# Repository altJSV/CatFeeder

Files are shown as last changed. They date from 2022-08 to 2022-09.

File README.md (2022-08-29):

# CatFeeder
- Автоматическая кормушка для домашних питомцев на esp8266
- Создана на основе оригинального проекта AlexGyver
- Страница проекта AlexGyver (схемы, описания): https://alexgyver.ru/gyverfeed2/
- Исходники скетча AlexGyver: https://github.com/AlexGyver/GyverFeed2/
- Идея переноса на esp8266 Sohm777 https://github.com/sohm777/feeder/

# Особенности
- Oled дисплей 
- Автоматическое выключение экрана при простое
- Управление 2 кнопками
- Полноценный веб интерфейс для управления устройством
- Часы с синхронизацией времени по протоколу NTP
- Управление по MQTT с возможной интеграцией в систему умного дома через Яндекс Алису или Home Asistent
- 4 независимых будильника для кормления в заданное время
- Возможность внеочередного кормления по нажатию кнопки, через веб интерфейс или отправки сообщения в MQTT топик
- Видимость и настройка порции кормления как через веб интерфейс, так и на oled экране
- Обновление прошивки по воздуху

# Компиляция и прошивка
Все использованные библиотеки находятся в папке libraries в архиве проекта. 
Настройки arduino ide для NodeMCU
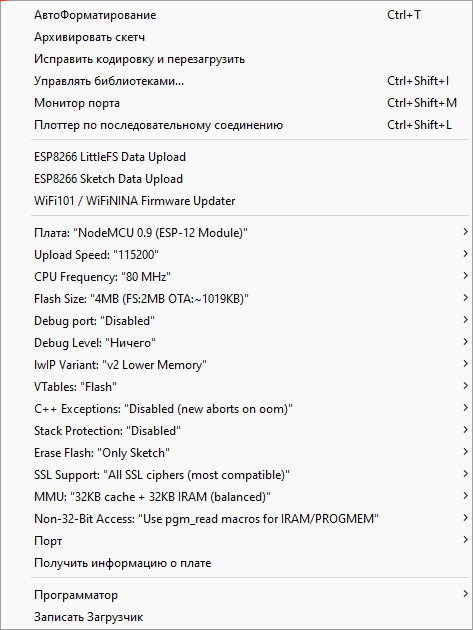
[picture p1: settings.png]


Файловую систему заливать вот по этому гайду https://wikihandbk.com/wiki/ESP8266:Прошивки/Arduino/Работа_с_файловой_системой_в_аддоне_ESP8266_для_IDE_Arduino , предварительно внеся в feeder.ino настройки WiFi и прочего. При последующих запусках настройки будут применены автоматически

# Схема подключения
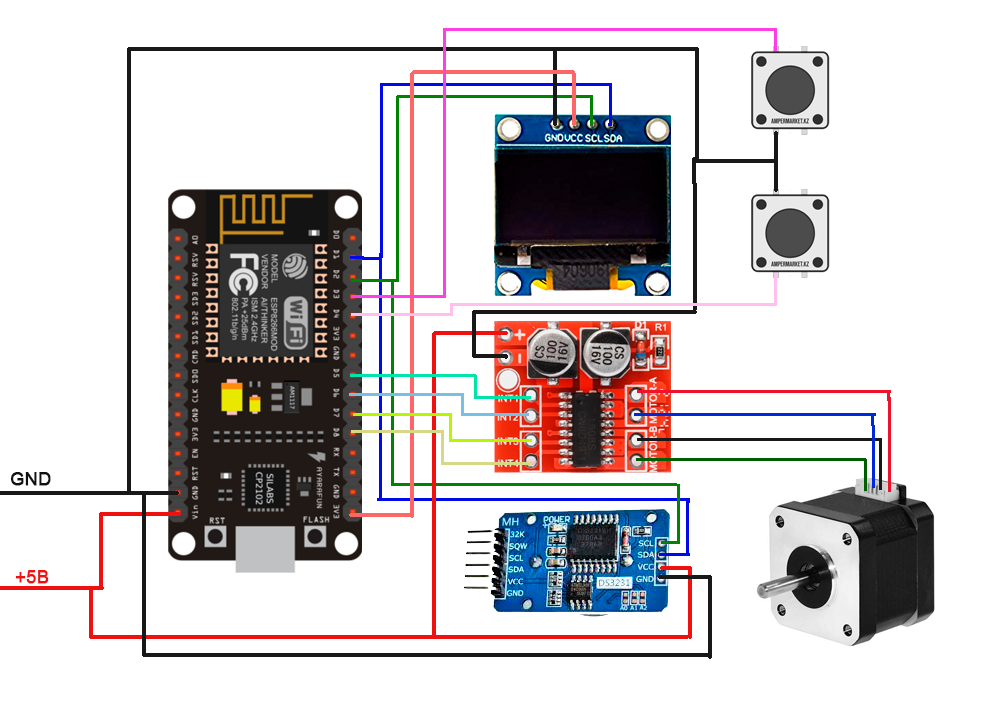
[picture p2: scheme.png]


# Веб интерфейс
При первом запуске, если вы проигнорировали предыдущий шаг, и не стали изменять настройки WiFi, либо кормушке не удалось подключиться к вашей сети WiFi, то устройство перейдет в режим точки доступа с именем CatFeeder и паролем 12345678. После чего запустит веб интерфейс по адресу 192.168.4.1, где вы сможете произвести все необходимые настройки. Если же подключение к вашей сети WiFi было успешным, то веб интерфейс будет доступен по адресу указанному на первом экране Oled дисплея

# Обновление прошивки
Обновление прошивки доступно либо через Arduino IDE>Скетч>Загрузка. Либо через веб интерфейс устройства по адресу http://ip.ad.re.ss/update
Обновление файловой системы можно так же осуществить несколькими способами.1) Arduino IDE>Инструменты>ESP8266 Sketch Data Upload 2)Через веб интерфейс устройства по адресу http://ip.ad.re.ss/update Поставить флажок возле Filesystem и загрузить fs.bin 3) Вручную через файловый менеджер по адресу http://ip.ad.re.ss/edit заменяя только необходимые файлы. Чаще всего в релизах меняется только index.html, так что если хотите быстро получить доступ к новым функциям без сброса настроек, то этот способ наиболее предпочтителен

# Управление кнопками
На основном экране. Одиночное нажатие Кнопки 1 - Выдать порцию корма. Одиночное нажатие Кнопки 2. Перейти на экран настройки будильников. Долгое нажатие кнопки 2. Перейти на экран настроек.
На экране будильников. Долгое нажатие Кнопки 2 - переход в режим редактирования. Короткое нажатие кнопки 2 - возврат на основной экран. В режиме редактирования Кнопка 1 - вверх, Кнопка 2 - вниз. Долгое нажатие Кнопки 1 - изменение настроек. Долгое нажатие Кнопки 2 - сохранение параметров и выход из режима редактирования
На экране настроек. Кнопка 1 - изменение. Кнопка 2 - переход к следующему пункту. Долгое нажатие Кнопки 2 - сохранение настроек и выход на основной экран

# MQTT
Для управления используется топик CatFeeder/feed. Список команд
- *feed* - выдать порцию
- *feam __xxx__* - установить размер порции. Где xx число от 0 до 99

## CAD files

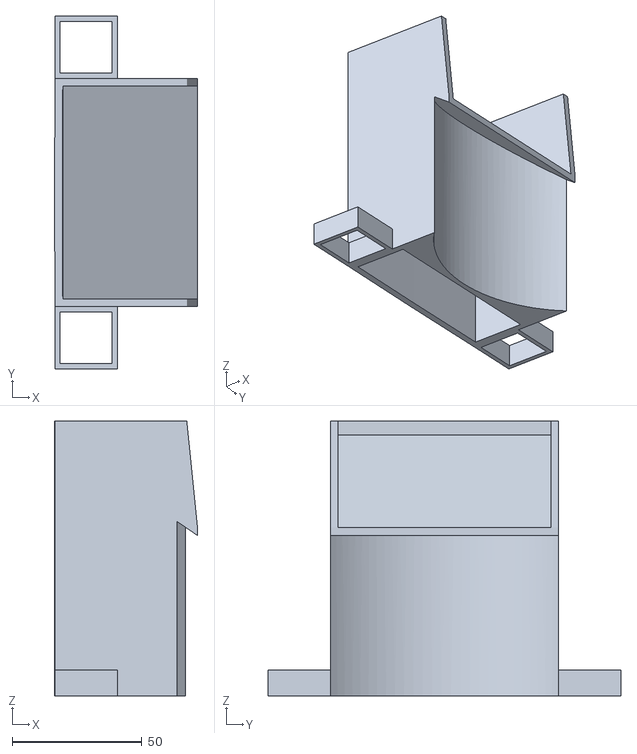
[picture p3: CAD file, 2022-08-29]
3d/cup_adapter.stl
55.1 x 136.0 x 106.0

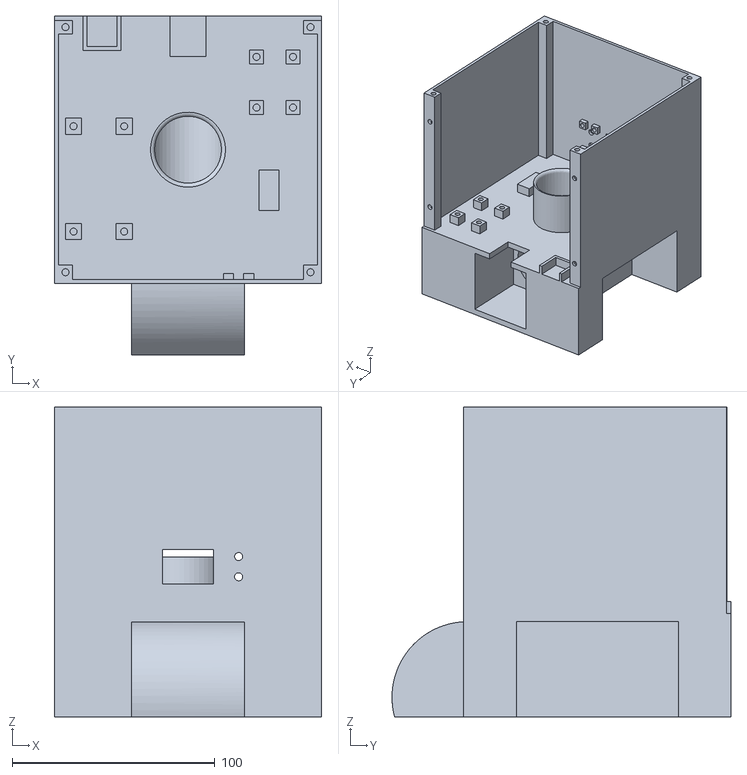
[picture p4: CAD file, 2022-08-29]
3d/box.stl
132.0 x 167.4 x 153.0

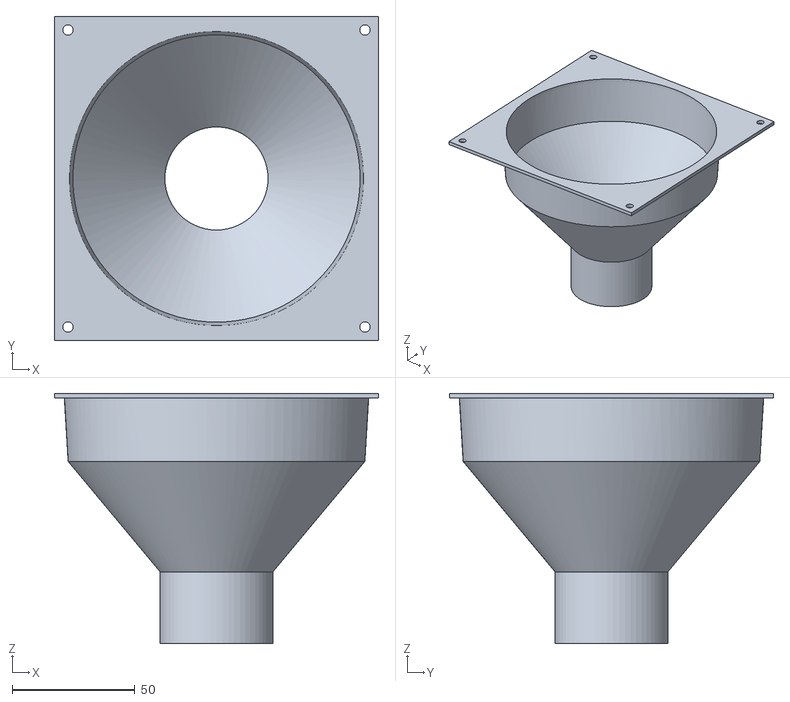
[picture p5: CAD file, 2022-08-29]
3d/bottle.stl
132.0 x 132.0 x 102.0

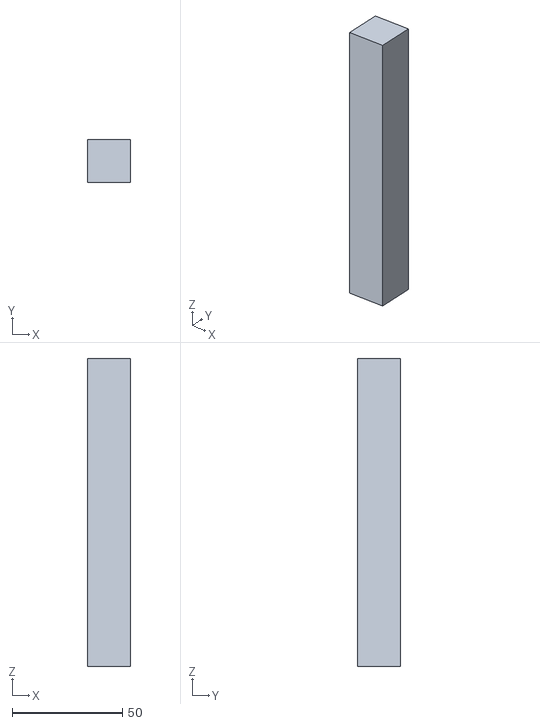
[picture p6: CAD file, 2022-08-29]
3d/legx4.stl
19.5 x 19.5 x 140.0

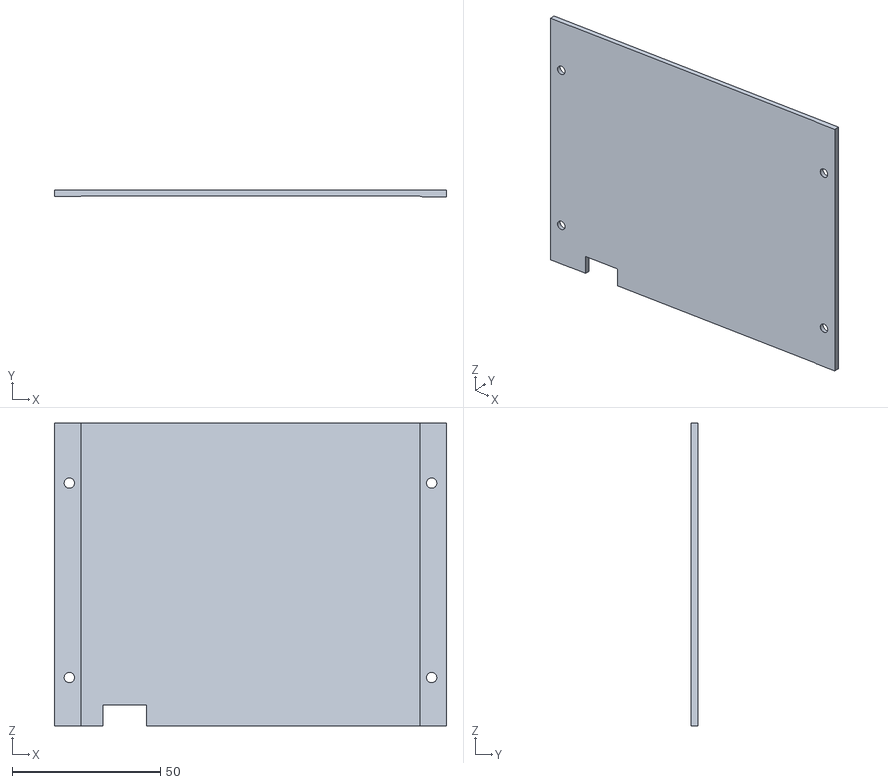
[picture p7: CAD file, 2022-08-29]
3d/back.stl
132.0 x 2.20 x 102.0

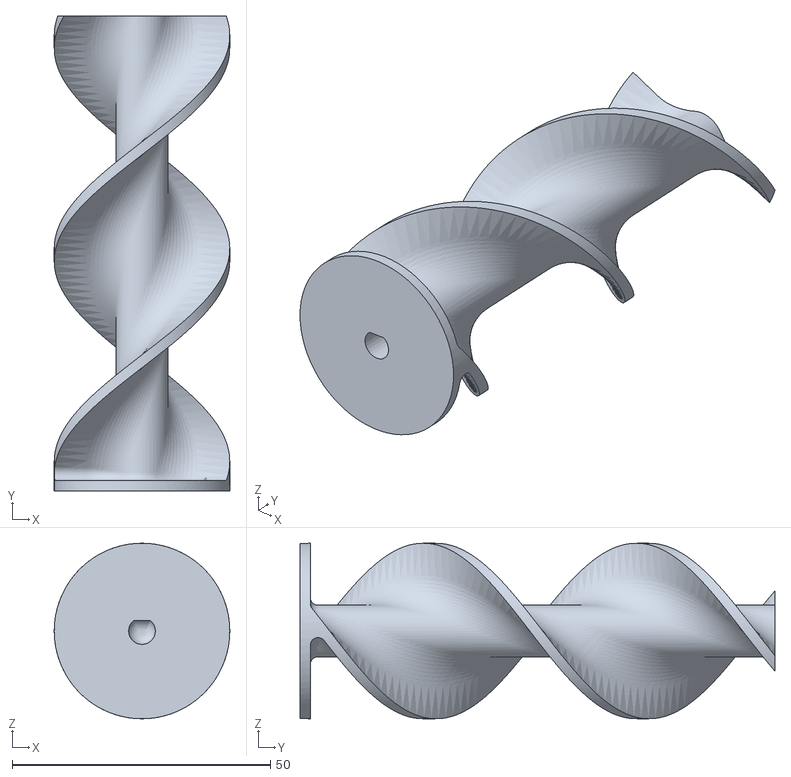
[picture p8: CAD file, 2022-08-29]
3d/screw.stl
34.0 x 92.0 x 34.0

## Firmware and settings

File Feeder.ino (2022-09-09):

/*
  Скетч к проекту "Автокормушка Wi-Fi"
  - Создан на основе оригинального скетча AlexGyver
  - Исходники этого проекта https://github.com/altJSV/CatFeeder/
  - Страница проекта AlexGyver (схемы, описания): https://alexgyver.ru/gyverfeed2/
  - Исходники скетча AlexGyver: https://github.com/AlexGyver/GyverFeed2/
*/

 byte feedTime[4][3] = {
  {6, 0, 1},                  // Часы, минуты, 0/1 выключен или включен
  {12, 0, 1},
  {18, 0, 1},
  {23, 50, 1},      
};
byte a_set=3; //вспомогательная переменная для установки будильников на экране
int FEED_SPEED=2000;    // задержка между шагами мотора  (мс)
byte STEPS_FRW=25;        // Шагов вперед
byte STEPS_BKW=18;

#define SCL 5               // D1
#define SDA 4               // D2

// driver - pins on the board (phaseА1 D5, phaseА2 D6, phaseВ1 D7, phaseВ2 D8)
const byte drvPins[] = {14, 12, 13, 15};


// =========================================================
#include "EncButton2.h"
#include <NTPClient.h>
#include <iarduino_RTC.h> 
iarduino_RTC rtc(RTC_DS3231);
#include <ESP8266WebServer.h>
#include <ESP8266WiFi.h>
#include <WiFiClient.h>
#include <Wire.h>
#include <SPI.h>  // не используется, но нужен RTCLib для компиляции
#include <Adafruit_GFX.h>
#include <Adafruit_SSD1306.h>
#include <ElegantOTA.h>
#include <WiFiUdp.h>
#include "GyverTimer.h"
#include <PubSubClient.h>
#include <FS.h>
#include <ArduinoJson.h>
#include <ESP8266SSDP.h>

//Настройки OLED дисплея
#define SCREEN_WIDTH 128 // OLED дисплей ширина в пикселях
#define SCREEN_HEIGHT 64 // OLED дисплей высота в пикселях
#define OLED_RESET     -1 
#define SCREEN_ADDRESS 0x3C //I2C адрес дисплея
Adafruit_SSD1306 display(SCREEN_WIDTH, SCREEN_HEIGHT, &Wire, OLED_RESET); //инициализация экрана


//MQTT настройки
const char* mqtt_server = "ip.ad.re.ss"; //ip или http адрес
int mqtt_port = 1883; //порт
const char* mqtt_login="login"; //логин
const char* mqtt_pass="pass"; //пароль

WiFiClient espClient;
PubSubClient client(espClient);


File fsUploadFile; //для файловой системы
int timezone = 3;

//NTP настройка
      WiFiUDP ntpUDP;
      NTPClient timeClient(ntpUDP, "pool.ntp.org", 3600*timezone);

//WiFi настройки
IPAddress apIP(192, 168, 4, 1); //IP точки доступа ESP8266
String ssid = "ssid"; //Название WIFI на роутере
String password = "pass";//Пароль WIFI роутера
String ssidAP="CatFeeder"; //Название точки доступа ESP8266
String passwordAP="12345678";//Пароль точки доступа ESP8266
String SSDP_Name = "CatFeeder"; // Имя SSDP. Под этим именем кормушка будет отображаться в сетевом окружении Windows
String last_feed="Котика никто не кормил"; //время последнего кормления

//Настройки меню
byte WorkMode = 0; //0 - рабочий режим 1-меню настроек
byte menuitem=0; //активный пункт меню
bool alarm_edit=false; //режим редактирования будильников
String jsonConfig = "{}"; //строка конфигурации для WEB морды
ESP8266WebServer server(80); //запускаем WEB сервер на 80 порту
//Установка таймеров
GTimer refscr(MS); //период обновления экрана
GTimer wificheck(MS); //проверка подключения к wifi;
GTimer rtcsync(MS); //синхронизация  RTC c NTP;
GTimer feedCheck(MS);//таймер кормления
GTimer reduceBright(MS);// снижение яркости дисплея при простое

//Объявление кнопок
EncButton2<EB_BTN> btn(INPUT,0); // D3 кнопка В1
EncButton2<EB_BTN> btn2(INPUT,2); //D4 кнопка В2
byte feedAmount = 25; //Размер порции. Нужен для первичной настройки. Далее будет читаться из конфига

//Прочие настройки
bool low_bright=false;
long scr_off_ms=60000;

void setup() {
  Serial.begin(115200);//Открытия COM порта для отладки
  
  // SSD1306_SWITCHCAPVCC = generate display voltage from 3.3V internally
  if(!display.begin(SSD1306_SWITCHCAPVCC, SCREEN_ADDRESS)) {
    Serial.println(F("SSD1306 allocation failed"));
    for(;;); // Don't proceed, loop forever
  }
  display.display();
  delay(2000); // Pause for 2 seconds

  // Вывод отладочной информации на OLED
  display.clearDisplay();
  display.setTextSize(1); // Draw 2X-scale text
  display.setTextColor(WHITE);
  display.setCursor(0, 4);

    Wire.begin();                       // I2C
    rtc.begin(); //Старт RTC
    timeClient.begin(); //NTP запуск склиента
    display.println("RTC OK..");
    FS_init();//Запуск файловой системы
    loadConfig(); //Чтение параметров из файла конфигурации
    WIFIinit();                         // Старт Wi-Fi
    display.println(WiFi.localIP());
    server_init(); //Запуск сервера
    if (WiFi.status() == WL_CONNECTED){
    display.print("Connected to ");
    display.println(ssid);  
    SSDP_init();
    MQTT_init();
    if (client.connected()) display.println ("MQTT OK");
    SetTime();
    display.println("RTC sync OK");
    }
    display.display();
refscr.setInterval(1000); //Интервал обновления экрана дисплея 1 секунда
wificheck.setInterval(60000);// Интервал между проверками соединения с wifi 1 минута
rtcsync.setInterval(3600000); //синхронизация  RTC c NTP каждый час
feedCheck.setInterval(500); //проверка таймеров кормления 1 раз в 31 секунду
if (scr_off_ms>0) reduceBright.setInterval(scr_off_ms); //снижение яркости при простое;
for (byte i = 0; i < 4; i++) pinMode(drvPins[i], OUTPUT);   // инициализация пинов драйвера шаговика
delay(5000);

}


void loop() {
   server.handleClient();//Веб сервер обновление страницы
 
    buttons_check(); //проверка нажатия кнопок
    timeClient.update();// синхронизация времени по NTP
  if (refscr.isReady()) { //обновление экрана
    draw_display();
  }
  if (rtcsync.isReady()) {
                          if (WiFi.status() == WL_CONNECTED) SetTime(); //Синхронизация времени rtc c ntp
                          }
                          
  if (wificheck.isReady()) {if (WiFi.getMode() !=WIFI_AP) {//Переподключение к WiFi если недоступен
                          if (WiFi.status() != WL_CONNECTED) {
                            WiFi.reconnect();
                            SSDP_init();
                            
                          }
                           }
                           if (!client.connected()) MQTT_init();
                           }

   if (feedCheck.isReady()){  //сработал будильник. Покормим котика
    static byte prevMin = 0;
    rtc.gettime();
    if (prevMin != rtc.minutes) {
      prevMin = rtc.minutes;
        for (byte i = 0; i < 4; i++)    // for the whole schedule
        if (feedTime[i][0] == rtc.Hours && feedTime[i][1] == rtc.minutes && feedTime[i][2] == 1 ) {   // время кормления
          feed();
        }
    }
   }


  if (scr_off_ms>0){
  if (reduceBright.isReady()){ //снижение яркости при простое
    if (low_bright==false){
      low_bright=true;
      display.dim(low_bright);
    }
    }
}
  client.loop(); //MQQT читает топики
  


}

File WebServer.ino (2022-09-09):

//WiFi Initialisation
void WIFIinit() {
   WiFi.mode(WIFI_STA);
  byte tries = 11;
  Serial.println();
  Serial.printf("Connecting to %s ", ssid);
  WiFi.begin(ssid, password);
  while (--tries && WiFi.status() != WL_CONNECTED) {
    Serial.print(".");
    delay(1000);
  }
  
  if (WiFi.status() != WL_CONNECTED) {
    Serial.println("Not connected");
    Serial.println("WiFi up Ap");
    StartAPMode();
     } else {
    Serial.print("Connected to ");
    Serial.println(ssid);
    Serial.print("Connected. IP: ");
    Serial.println(WiFi.localIP());
    WiFi.persistent(true);
  ElegantOTA.begin(&server);    // Start ElegantOTA update server
     }
}


bool StartAPMode()
{ // Отключаем WIFI
  WiFi.disconnect();
  // Меняем режим на режим точки доступа
  WiFi.mode(WIFI_AP);
  // Задаем настройки сети
  WiFi.softAPConfig(apIP, apIP, IPAddress(255, 255, 255, 0));
  // Включаем WIFI в режиме точки доступа с именем и паролем
  // хронящихся в переменных _ssidAP _passwordAP
  WiFi.softAP(ssidAP, passwordAP);
  return true;
}

   void MQTT_init(){  
  //MQQT initialize
  static uint32_t tmr = 0;
  client.setServer(mqtt_server, mqtt_port);
  client.setCallback(MQTTcallback);
  byte tries=10;
  while (--tries && !client.connected()) 
  {   
     Serial.println("Connecting to MQTT...");
     if (client.connect("CatFeeder", mqtt_login,mqtt_pass))
       {
      Serial.println("connected");
      client.publish("CatFeeder/status","Ok");
      client.subscribe("CatFeeder/feed");
      }
    else
    {
      Serial.print("failed with state ");
      Serial.println(client.state());
      }
  }
  
   delay(2000);
   }


void SSDP_init(void) {
  // SSDP дескриптор
  server.on("/description.xml", HTTP_GET, []() {
    SSDP.schema(server.client());
  });
  //Если версия  2.0.0 закаментируйте следующую строчку
  SSDP.setDeviceType("upnp:rootdevice");
  SSDP.setSchemaURL("description.xml");
  SSDP.setHTTPPort(80);
  SSDP.setName(SSDP_Name);
  SSDP.setSerialNumber("001788102201");
  SSDP.setURL("/");
  SSDP.setModelName("CatFeeder");
  SSDP.setModelNumber("000000000001");
  SSDP.setManufacturer("Yarovoy Sergey");
   SSDP.begin();
}

void server_init(void) {
  server.on("/restart", handle_Restart); // Перезагрузка модуля по запросу вида http://192.168.0.101/restart?device=ok
  server.on("/configs.json", handle_ConfigJSON); // формирование configs.json страницы для передачи данных в web интерфейс
  // API для устройства
  server.on("/ssdp", handle_Set_Ssdp);     // Установить имя SSDP устройства по запросу вида /ssdp?ssdp=proba
  server.on("/ssid", handle_Set_Ssid);     // Установить имя и пароль роутера по запросу вида /ssid?ssid=home2&password=12345678
  server.on("/ssidap", handle_Set_Ssidap); // Установить имя и пароль для точки доступа по запросу вида /ssidap?ssidAP=home1&passwordAP=8765439
  server.on("/TimeZone", handle_time_zone);    // Установка времянной зоны по запросу вида http://192.168.0.101/TimeZone?timezone=3
  server.on("/Time", handle_Time);
  server.on("/FeedAmount", handle_feed_amount);    // Установка времянной зоны по запросу вида http://192.168.0.101/TimeZone?timezone=3
  server.on("/Alarms",handle_alarms);
  server.on("/feed",handle_feed);
  server.on("/time_scr",handle_time_scr);
  server.on("/status",handle_status_page);
  server.on("/set_steps",handle_set_steps);
  server.begin();
  Serial.println("HTTP server started");  
}


// Функции API-Set
// Установка SSDP имени по запросу вида http://192.168.0.101/ssdp?ssdp=proba
void handle_Set_Ssdp() {
  SSDP_Name = server.arg("ssdp"); // Получаем значение ssdp из запроса сохраняем в глобальной переменной
  saveConfig();                 // Функция сохранения данных во Flash пока пустая
  server.send(200, "text/plain", "OK"); // отправляем ответ о выполнении
}

void handle_set_steps() {
  FEED_SPEED = server.arg("step_d").toInt(); // Получаем значение ssdp из запроса сохраняем в глобальной переменной
  STEPS_FRW = server.arg("step_f").toInt();       // Шагов вперед
  STEPS_BKW = server.arg("step_b").toInt();
  saveConfig();                 // Функция сохранения данных во Flash пока пустая
  server.send(200, "text/plain", "OK"); // отправляем ответ о выполнении
}

void handle_time_scr() {
  int temp_time_scr;
  temp_time_scr = server.arg("time_scr").toInt(); // Получаем значение time_scr из запроса сохраняем в глобальной переменной
  scr_off_ms=temp_time_scr*1000;
  if (temp_time_scr>0){
  reduceBright.setInterval(scr_off_ms);  
  }
  else reduceBright.stop();
  saveConfig();                 // Функция сохранения данных во Flash пока пустая
  server.send(200, "text/plain", "OK"); // отправляем ответ о выполнении
}

// Установка параметров для подключения к внешней AP по запросу вида http://192.168.0.101/ssid?ssid=home2&password=12345678
void handle_Set_Ssid() {
  ssid = server.arg("ssid");            // Получаем значение ssid из запроса сохраняем в глобальной переменной
  password = server.arg("password");    // Получаем значение password из запроса сохраняем в глобальной переменной
  saveConfig();                        // Функция сохранения данных во Flash пока пустая
  server.send(200, "text/plain", "OK");   // отправляем ответ о выполнении
}

void handle_feed() {
  feed();
  server.send(200, "text/plain", "OK");   // отправляем ответ о выполнении
}
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

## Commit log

2022-08-29 Add screen off timer
2022-08-31 Status page, fix bugs, mqtt commands
    [Feeder.ino, FileConfig.ino, WebServer.ino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]
2022-09-03 Фикс времени срабатывания таймера
2022-09-03 Переподкючение к MQTT при обрыве связи
2022-09-04 Фикс будильника
2022-09-09 В веб интерфейс добавлена настройка движения шнека
